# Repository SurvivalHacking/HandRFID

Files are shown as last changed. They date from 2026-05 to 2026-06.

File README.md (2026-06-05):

# HandRFID
Portable RFID tag reader-writer for filaments / Lettore-Scrittore di TAG RFID per filamenti

## 📘 Description / Descrizione

A small, portable device that allows you to quickly write RFID tags to label your spools. Compatible with QIDI and ANYCUBIC systems, but can be updated to support other standards as they become more widespread. / Un piccolo dispositivo portatile, che consente la scrittura rapida dei TAG RFID per battezzare le vostre bobine. Compatibile con sistemi QIDI e ANYCUBIC, ma aggiornabile per altri standard che prenderanno piede.

* Battery-powered / Funzionante a batterie
* Touchscreen / Touch Screen
* Material database / Database materiali
* Manufacturer database / Database costruttori
* Web-configurable / Configurabile via WEB
* Easy to implement / Facile da realizzare

Video tutorial (Italian): https://youtu.be/M0HzzsOZAlI 

Screenshot 2026-05-03 alle 01 08 40
Screenshot 2026-05-03 alle 01 08 11
Screenshot 2026-05-03 alle 01 07 57
Screenshot 2026-05-03 alle 01 07 41
Screenshot 2026-05-03 alle 01 07 27
Screenshot 2026-05-03 alle 01 05 34
Screenshot 2026-05-03 alle 01 05 09
Screenshot 2026-05-03 alle 01 04 54
Screenshot 2026-05-03 alle 01 14 26
Screenshot 2026-05-03 alle 01 13 25

## 👨‍💻 Programming / Programmazione

* WEB Programming (only for chrome) / Programmatore WEB (Solo per chrome): [https://youtu.be/M0HzzsOZAlI ](https://davidegatti.altervista.org/installaEsp32.php?progetto=HandRFID)

---
## 🎛️ Practical Assembly Guide / Schema pratico di assemblaggio

Schematic

---
## 🎛️ BOM / Elenco materiali

* PN532: https://s.click.aliexpress.com/e/_c30J9g7Z
* ESP32-2432S024R: https://s.click.aliexpress.com/e/_c3bvlCXF
* Mifare Classic 1K: https://s.click.aliexpress.com/e/_c3QRUTPz
* NTAG 213: https://s.click.aliexpress.com/e/_c3fpyESh
* Battery 803040 1000mA: https://s.click.aliexpress.com/e/_c4LtLOBT
* Link Affiliati

---
# 📝 Revisions / Revisioni

V1.0
* First Version / Prima versione

V1.1 - 21/02/2025
* Fixed some colour identification and minor bugs / Sistemati alcune rilevazioni colore e bug minori

V1.2 / V1.2C - 05/06/2026
* Added French Language / Aggiunta lingua francese

V1.2C - 05/06/2026 
* Special version for CYD ESP32-024 Clone / Versione speciale per CYD ESP32-024 Clone

---
## 🧾 License / Licenza

This project is licensed under
**Creative Commons Attribution-NonCommercial 4.0 International (CC BY-NC 4.0)**.

You may freely share and modify it, **citing the author**
(Davide Gatti / [survivalhacking](https://github.com/survivalhacking)) and Paolo Sambinello  **for non-commercial purposes**.

Questo progetto è distribuito con licenza
**Creative Commons – Attribuzione – Non Commerciale 4.0 Internazionale (CC BY-NC 4.0)**.

Puoi condividerlo e modificarlo liberamente, **citando l’autore**
(Davide Gatti / [survivalhacking](https://github.com/survivalhacking)) e Paolo Sambinello  **senza scopi commerciali**.

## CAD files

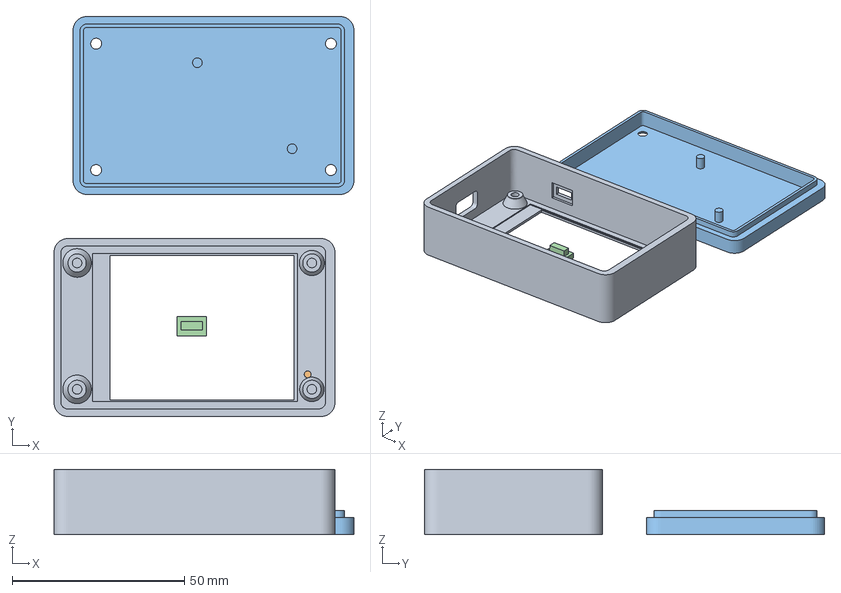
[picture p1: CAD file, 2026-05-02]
3D/BOX FULL (QIDI).3mf
87.1 x 116.2 x 18.9 mm
BOT
BOT-BIANCO
top
Pulsante.stl

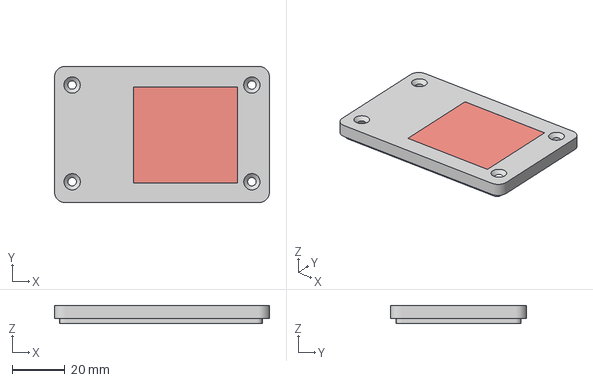
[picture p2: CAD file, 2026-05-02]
3D/BOT.3mf
81.6 x 51.7 x 7.00 mm
COLOR
Corpo26

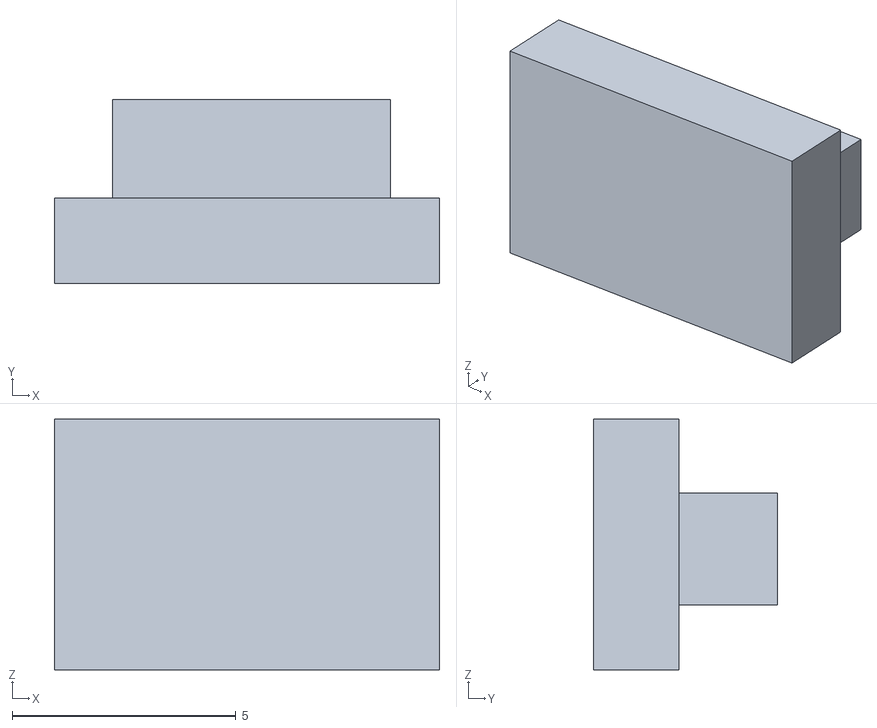
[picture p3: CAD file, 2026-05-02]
3D/Button.stl
8.60 x 4.10 x 5.60

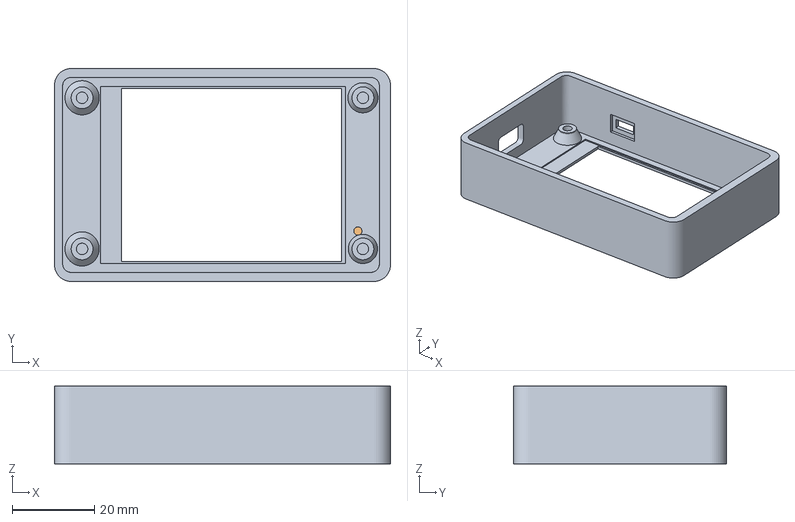
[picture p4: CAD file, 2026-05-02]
3D/TOP.3mf
81.6 x 51.7 x 18.9 mm
BOT
BOT-BIANCO

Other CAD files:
3D/BOX FULL (BAMBULAB).3mf
3D/BOX FULL (ANYCUBIC).3mf
3D/RFID.f3d

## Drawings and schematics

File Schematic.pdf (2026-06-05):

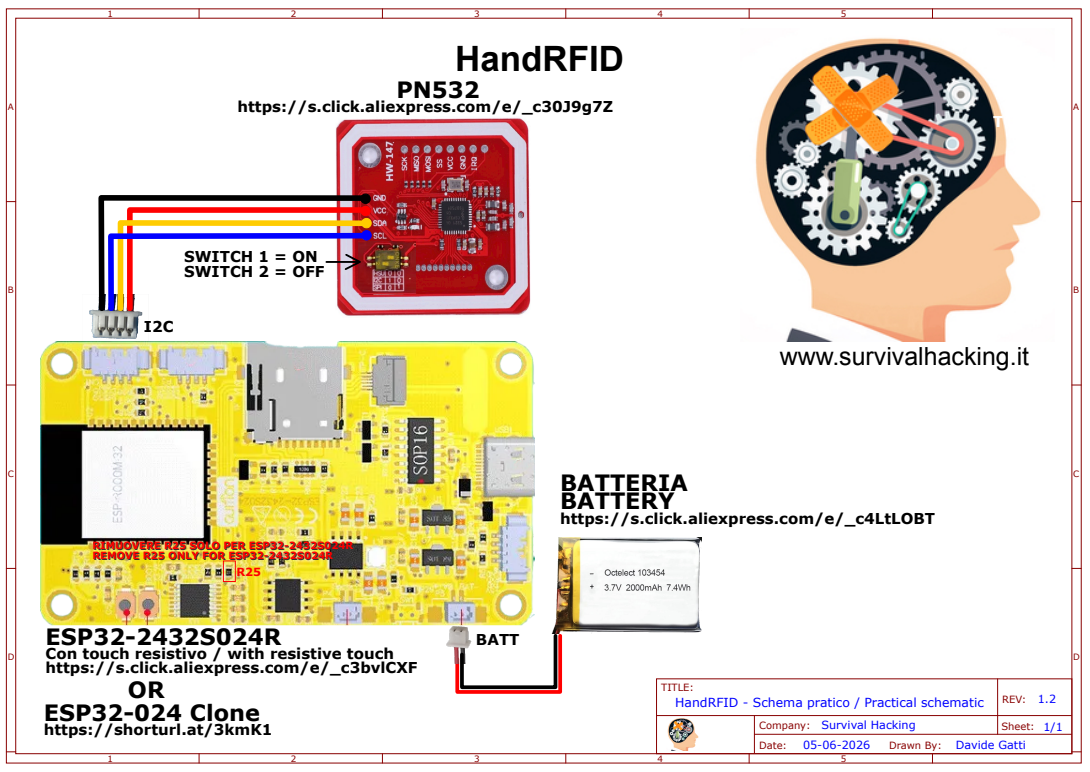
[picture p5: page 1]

https://s.click.aliexpress.com/e/_c30J9g7Z

BATTERIA
BATTERY
https://s.click.aliexpress.com/e/_c4LtLOBT

ESP32-2432S024R
Con touch resistivo / with resistive touch
https://s.click.aliexpress.com/e/_c3bvlCXF
ESP32-024 Clone
https://shorturl.at/3kmK1

TITLE: HandRFID - Schema pratico / Practical schematic | REV: 1.2

Company: Survival Hacking | Sheet: 1/1

Drawn By: Davide Gatti

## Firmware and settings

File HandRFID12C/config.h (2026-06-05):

// ============================================================
//  HandRFID-Touch – Hardware Configuration
//  Target boards: ESP32-2432S024R/C (2.4") / ESP32-2432S028R (2.8")
//  S024: resistive (XPT2046) + capacitive (CST820) auto-detect
//  S028: resistive only (XPT2046 on SPI bus separato)
//  Reconstructed from V2.1 firmware for S028R
// ============================================================
#pragma once

// ============================================================
//  DISPLAY SELECTION – uncomment ONE of the following
//  *** Cambiare anche in User_Setup.h (copiato nella libreria TFT_eSPI) ***
// ============================================================
#define DISPLAY_24    // ESP32-2432S024R/C – 2.4" CYD
// #define DISPLAY_28  // ESP32-2432S028R/C – 2.8" CYD

// ---- Validate selection ----
#if defined(DISPLAY_24) && defined(DISPLAY_28)
  #error "Select only ONE display: DISPLAY_24 or DISPLAY_28"
#elif !defined(DISPLAY_24) && !defined(DISPLAY_28)
  #error "Select a display: uncomment DISPLAY_24 or DISPLAY_28"
#endif

// ---------- Display (ILI9341 on HSPI) ----------
#define TFT_MOSI  13
#define TFT_MISO  12
#define TFT_SCLK  14
#define TFT_CS    15
#define TFT_DC     2
#define TFT_RST   -1          // tied to EN on CYD boards

// *** S024R/C vs S028R/C: backlight and I2C SDA are swapped ***
#ifdef DISPLAY_24
  #define TFT_BL    27
#else
  #define TFT_BL    21
#endif
#define TFT_BACKLIGHT_ON HIGH

// ---------- Touch – Resistive XPT2046 ----------
#define TOUCH_CS   33
#define TOUCH_IRQ  36

#ifdef DISPLAY_24
  // S024: touch condivide HSPI con il display (stessi MOSI/MISO/SCLK)
#else
  // S028: touch su bus SPI separato (pin dedicati)
  #define TOUCH_MOSI  32
  #define TOUCH_MISO  39
  #define TOUCH_CLK   25
#endif

// ---------- Touch – Capacitive CST820 (solo S024C, auto-detect) ----------
#ifdef DISPLAY_24
  #define CTP_SDA    33
  #define CTP_SCL    32
  #define CTP_RST    25
  #define CTP_INT    21
#endif

// ---------- I2C for PN532 NFC ----------
#ifdef DISPLAY_24
  #define I2C_SDA   21  //1        // S024R/C: GPIO 21
  #define I2C_SCL   22  //3        // same on both boards
#else
  #define I2C_SDA   27        // S028R/C: GPIO 27
  #define I2C_SCL   22          // same on both boards
#endif
#define PN532_I2C_ADDR 0x24

// ---------- RGB LED (active LOW on CYD) ----------
#define LED_R      4
#define LED_G     16
#define LED_B     17

// ---------- NVS namespace ----------
#define NVS_NAMESPACE "touch"

// ---------- Firmware version ----------
#ifdef DISPLAY_24C
  #define FW_VERSION "1.2C-S024C"
#elif defined(DISPLAY_24)
  #define FW_VERSION "1.2C-S024"
#else
  #define FW_VERSION "1.2C-S028"
#endif
// ---------- Display ----------
#define SCREEN_W 240
#define SCREEN_H 320

// ---------- MIFARE Classic 1K (QIDI) ----------
// QIDI usa sector 1 block 0 = absolute block 4
// Formato: byte[0]=Material code, byte[1]=Color code(1-24), byte[2]=Manufacturer(0=Generic,1=QIDI)
#define QIDI_DATA_BLOCK   4
// Keys da provare in ordine: {key[6], keyType} — keyType: 0=A, 1=B
#define QIDI_NUM_KEYS     8
struct QidiKeyEntry { uint8_t key[6]; uint8_t type; };
static const QidiKeyEntry QIDI_KEYS[QIDI_NUM_KEYS] = {
  {{0x1B, 0xFF, 0xFF, 0xFF, 0xFF, 0xFF}, 0},  // Key A primaria QIDI
  {{0x00, 0x00, 0x00, 0x00, 0x00, 0x00}, 1},  // Key B zeros (common)
  {{0xFF, 0xFF, 0xFF, 0xFF, 0xFF, 0xFF}, 0},  // Key A default factory
  {{0xFF, 0xFF, 0xFF, 0xFF, 0xFF, 0xFF}, 1},  // Key B default factory
  {{0xA0, 0xA1, 0xA2, 0xA3, 0xA4, 0xA5}, 0},  // Key A MAD
  {{0xD3, 0xF7, 0xD3, 0xF7, 0xD3, 0xF7}, 0},
  {{0x00, 0x00, 0x00, 0x00, 0x00, 0x00}, 0},  // Key A zeros
  {{0xB0, 0xB1, 0xB2, 0xB3, 0xB4, 0xB5}, 0},
};

// Codici materiale QIDI (NON sequenziali!)
struct QidiMatCode { const char* name; uint8_t code; };
#define QIDI_MAT_CODE_COUNT 36
static const QidiMatCode qidiMatCodes[QIDI_MAT_CODE_COUNT] = {
  {"PLA",        1}, {"PLA Matte",  2}, {"PLA Metal",  3}, {"PLA Silk",   4},
  {"PLA-CF",     5}, {"PLA-Wood",   6}, {"PLA-Basic",   7}, {"PLA-Matte Bas",  8},
  {"ABS",       11}, {"ABS-GF",    12}, {"ABS-Metal", 13}, {"ABS-OdorLess",  14},
  {"ASA",       18}, {"ASA-AERO",  19},
  {"PA",        24}, {"PA-CF",     25}, {"UltaPA-CF25", 26}, {"PA12-CF",     27},
  {"PAHT-CF",   30}, {"PAHT-GF",   31}, {"Supp.-PATH",  32}, {"Sup.-PET/PA", 33},
  {"PC/ABS-FR", 34},
  {"PET-CF",    37}, {"PET-GF",    38}, {"PETG-Basic",  39}, {"PETG-Tough",  40},
  {"PETG",      41}, {"PETG-CF",   42}, {"PETG Rapido", 43},
  {"PPS-CF",    44}, {"PETG-TR",   45}, {"PPS-GF",      46},
  {"PVA",       47}, {"TPU-Aero",  49},
  {"TPU",       50},
};

// Palette colori condivisa Qidi/Anycubic
// rgb = colore RGB24, qidiCode = codice Qidi 1-24 (0 = solo Anycubic)
struct ColorEntry { uint32_t rgb; uint8_t qidiCode; const char* nameEN; const char* nameIT; };
#define COLOR_PALETTE_COUNT 28
static const ColorEntry colorPalette[COLOR_PALETTE_COUNT] = {
  // --- Colori Qidi (qidiCode 1-24) ---
  {0xFAFAFA,  1, "White",       "Bianco"},
  {0x060606,  2, "Black",       "Nero"},
  {0xD9E3ED,  3, "Silver",      "Argento"},
  {0x5CF30F,  4, "Light Green", "Verde chiaro"},
  {0x63E492,  5, "Mint",        "Menta"},
  {0x2850FF,  6, "Blue",        "Blu"},
  {0xFE98FE,  7, "Pink",        "Rosa"},
  {0xDFD628,  8, "Yellow",      "Giallo"},
  {0x228332,  9, "Green",       "Verde"},
  {0x99DEFF, 10, "Light Blue",  "Azzurro"},
  {0x1714B0, 11, "Dark Blue",   "Blu scuro"},
  {0xCEC0FE, 12, "Lavender",    "Lavanda"},
  {0xCADE4B, 13, "Lime",        "Lime"},
  {0x1353AB, 14, "Royal Blue",  "Blu reale"},
  {0x5EA9FD, 15, "Sky Blue",    "Blu cielo"},
  {0xA878FF, 16, "Violet",      "Viola"},
  {0xFE717A, 17, "Rose",        "Rosato"},
  {0xFF362D, 18, "Red",         "Rosso"},
  {0xE2DFCD, 19, "Beige",       "Beige"},
  {0x898F9B, 20, "Gray",        "Grigio"},
  {0x6E3812, 21, "Brown",       "Marrone"},
  {0xCAC59F, 22, "Khaki",       "Kaki"},
  {0xF28636, 23, "Orange",      "Arancione"},
  {0xB87F2B, 24, "Bronze",      "Bronzo"},
  // --- Colori extra Anycubic (qidiCode = 0, no mapping Qidi) ---
  {0x00FFFF,  0, "Cyan",        "Ciano"},
  {0x8000FF,  0, "Purple",      "Porpora"},
  {0xFF69B4,  0, "Hot Pink",    "Rosa acceso"},
  {0xFFD700,  0, "Gold",        "Oro"},
};
#define MIFARE_BLOCKS 64
#define MIFARE_BLOCK_SIZE 16

// ---------- NTAG (Anycubic) – page layout ----------
#define ACE_PAGE_HEADER     4
#define ACE_PAGE_SKU        5   // 5-8   (20 bytes, 5 pages)
#define ACE_PAGE_BRAND     10   // 10-13 (16 bytes, 4 pages)
#define ACE_PAGE_TYPE      15   // 15-18 (16 bytes, 4 pages)
#define ACE_PAGE_COLOR     20   // 20    (4 bytes ABGR)
#define ACE_PAGE_EXT_TEMP  24   // 24    (4 bytes: min16LE + max16LE)
#define ACE_PAGE_BED_TEMP  29   // 29    (4 bytes: min16LE + max16LE)
#define ACE_PAGE_FILAMENT  30   // 30    (4 bytes: diameter16LE + length16LE)
#define ACE_PAGE_UNK       31   // 31    (E8 03 00 00)
#define ACE_HEADER_MAGIC   {0x7B, 0x00, 0x65, 0x00}
#define ACE_BRAND_DEFAULT  "AC"
#define ACE_SKU_LEN        20
#define ACE_STR_LEN        16

// ---------- WiFi (WiFiManager + web editor) ----------
#define WIFI_PORTAL_SSID "HandRFID-Setup"  // nome AP per config portal
#define WIFI_PORTAL_PASS "handrfid1"       // password AP config portal
#define WIFI_PORTAL_TIMEOUT 120            // secondi timeout config portal
#define WEB_PORT         80

// ---------- SPIFFS ----------
#define CSV_PATH         "/materials.csv"

// ---------- Material/Manufacturer DB ----------
#define MAX_MATERIALS       40
#define MAX_MANUFACTURERS   20
#define MAX_ACE_MATERIALS   20
#define MAT_NVS_NS   "matdb"
#define MFG_NVS_NS   "mfgdb"
#define MAT_KEY_FMT  "m%02u"

// ---------- Default manufacturers ----------
#define DEFAULT_MFG_1 "QIDI"
#define DEFAULT_MFG_2 "Anycubic"
#define DEFAULT_MFG_3 "Generic"

// ---------- Anycubic material entry (dynamic, loaded from SPIFFS) ----------
struct AceMatEntry {
  char     name[24];
  char     sku[24];
  uint16_t extMin, extMax;
  uint16_t bedMin, bedMax;
  bool     used;
};


// Weight -> length (meters) lookup
#define ACE_WEIGHT_COUNT 5
struct AceWeightEntry { const char* label; uint16_t grams; uint16_t meters; };
static const AceWeightEntry aceWeightDB[ACE_WEIGHT_COUNT] = {
  {"250g",   250,   82},
  {"500g",   500,  165},
  {"600g",   600,  198},
  {"750g",   750,  247},
  {"1000g", 1000,  330},
};

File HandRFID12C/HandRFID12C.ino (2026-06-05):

// ============================================================
//  HandRFID V1.2C
//  By Paolo Sambinello e Davide Gatti  www.survivalhacking.it
//  GITHUB: https://github.com/SurvivalHacking/handrfid
//
//  Dispositivo portatile per la gestione pratica dei TAG RFID delle bobine dei filamenti QIDI e ANYCUBIC / 
//  Handheld device for QIDI and ANYCUBIC reel RFID TAG 
//  * Gestione costruttori / Manufacturer management 
//  * Gestione Materiali / Material management
//  * Configurabile via WEB / Cofigurable via WEB
//  * Open Source e personalizzabile / Open source full customizable 
//
//  Elenco materiali / Bill of material
//  PN532: https://s.click.aliexpress.com/e/_c30J9g7Z (ATTENZIONE/WARNING  SW1=ON SW2=OFF)
//  ESP32-2432S024R: https://s.click.aliexpress.com/e/_c3bvlCXF
//  Batt. 803040 1000mA: https://s.click.aliexpress.com/e/_c4LtLOBT	
//
//  TAG Adesivi / adhesive TAG
//  Mifare Classic 1K: https://s.click.aliexpress.com/e/_c3QRUTPz
//  NTAG 213: https://s.click.aliexpress.com/e/_c3fpyESh
//
//  Copiare il file User_Setup.h nella cartella [utente]/documenti/arduino/libraries/TFT_eSPI	
//  Copy the file User_Setup.h on folder [users]/document/arduino/libraries/TFT_eSPI	
//
//  V1.0 15/03/2026 By Paolo Sambinello e Davide Gatti
//  Release iniziale / Initial release
//
//  V1.1 18/04/2026 by Davide Gatti
//  Sistemati alcuni problemi che facevano mostrare dati in modo non preciso. A volte mancava il costruttore e a volte il colore non aveva il nome ma un codice e non venivano rilevati correttamente i TAG vuoti
//
//  V1.2C 05/06/2022 by Davide Gatti
//  Aggiunta lingua Francese
//  Versione dedicata per il display CYD Clone ESP32-024  https://shorturl.at/3kmK1
//
// ============================================================




#include <Wire.h>
#include <SPI.h>
#include <Preferences.h>
#include <TFT_eSPI.h>
#include <XPT2046_Touchscreen.h>
#include <Adafruit_PN532.h>
#include <FS.h>
using namespace fs;        // espone File, FS nel global scope (richiesto da WebServer ESP32 core 3.x)
#include <SPIFFS.h>
#include <WiFi.h>
#include <WebServer.h>
#include <WiFiManager.h>
#include "qrcode.h"
#include <time.h>              // NTP time

#include "config.h"
#include "lang.h"
#include "utf8_latin1.h"
#include "FreeSans9pt8b.h"
#include "FreeSansBold12pt8b.h"
#include "webui.h"
#include "logo.h"
#ifdef DISPLAY_24
  #include "CST820.h"
#endif

// ---- Button struct (must be before any function using it) ----
struct Btn { int x, y, w, h; const char* label; uint16_t bg; };

// ---- Fonts (FreeSans = Arial equivalent) ----
// Inclusi tramite TFT_eSPI con LOAD_GFXFF abilitato
#define FONT_TITLE  &FreeSansBold12pt8b   // titoli / header (Latin-1 extended)
#define FONT_BODY   &FreeSans9pt8b        // testo normale (Latin-1 extended)
#define FONT_SMALL  &FreeSans9pt8b        // testo piccolo (Latin-1 extended)

// ---- Touch type ----
#ifdef DISPLAY_24
  enum TouchType { TOUCH_NONE, TOUCH_RESISTIVE, TOUCH_CAPACITIVE };
#else
  enum TouchType { TOUCH_NONE, TOUCH_RESISTIVE };  // S028: solo resistivo
#endif
TouchType touchType = TOUCH_NONE;

// ---- Globals ----
TFT_eSPI tft = TFT_eSPI();

// Font helpers (must be after tft declaration)
void setFontTitle() { tft.setFreeFont(FONT_TITLE); tft.setTextSize(1); }
void setFontBody()  { tft.setFreeFont(FONT_BODY);  tft.setTextSize(1); }
void setFontSmall() { tft.setFreeFont(FONT_SMALL); tft.setTextSize(1); }
void setFontBuiltin() { tft.setTextFont(1); tft.setTextSize(1); }

#ifdef DISPLAY_28
  // S028: touch XPT2046 su bus SPI dedicato (GPIO 32/39/25)
  SPIClass touchSPI(VSPI);
  XPT2046_Touchscreen ts(TOUCH_CS, TOUCH_IRQ);
#else
  // S024: touch XPT2046 condivide HSPI col display
  XPT2046_Touchscreen ts(TOUCH_CS, TOUCH_IRQ);
#endif

#ifdef DISPLAY_24
  // S024: capacitive CST820 (auto-detect)
  CST820 ctp(CTP_SDA, CTP_SCL, CTP_RST, -1);  // INT=-1 to avoid GPIO 21 conflict
#endif

Adafruit_PN532 nfc(-1, -1, &Wire);     // I2C mode on Wire (GPIO 21/22)
Preferences prefs;
WebServer server(WEB_PORT);

// ---- Dynamic material databases (loaded from SPIFFS CSV) ----
AceMatEntry aceMatList[MAX_ACE_MATERIALS];
uint8_t     aceMatCount = 0;

// ---- Debug log panel ----
#define DBG_MAX_LINES  10
#define DBG_LINE_LEN   36
char   dbgLines[DBG_MAX_LINES][DBG_LINE_LEN];
int    dbgCount = 0;    // quante righe totali scritte
int    dbgStart = 0;    // indice circolare della riga piu vecchia

// ---- State ----
bool   showDebugPanel = false;  // visibilita pannello debug (default OFF)
bool   wifiEnabled    = false;  // WiFi abilitato on-demand (default OFF)
bool   wifiConnected = false;
bool   webServerStarted = false;  // server.begin() chiamato solo dopo WiFi
Lang   curLang       = LANG_IT;
bool   displayInvert = false;
bool   autoMode      = false;
bool   nfcPresent    = false;
bool   nfcBusy       = false;
bool   hasCalib      = false;
int    calibMinX = 200, calibMaxX = 3900;
int    calibMinY = 200, calibMaxY = 3900;

// ---- Tag mode (QIDI vs Anycubic) ----
enum TagMode { TAG_QIDI, TAG_ANYCUBIC };
TagMode writeMode = TAG_QIDI;   // selected write mode
TagMode lastReadMode = TAG_QIDI; // detected on last read

// Current selection for writing (QIDI)
uint8_t selMfgIdx    = 0;   // manufacturer index
uint8_t selMatIdx    = 0;   // material index
uint8_t selColorIdx  = 0;   // color index

// Current selection for writing (Anycubic)
uint8_t selAceMatIdx    = 0;  // index into aceMatList
uint8_t selAceWeightIdx = 2;  // index into aceWeightDB (default 600g)
uint8_t selAceColorIdx  = 1;          // index into colorPalette (default Black)
String   selAceBrand    = "AC";       // "AC" = Anycubic, "GEN" = Generic

// Scroll offset (shared across list screens, reset on screen change)
int scrollOffset = 0;

// Timers
unsigned long lastTouchTime = 0;
unsigned long lastActivityTime = 0;
unsigned long screensaverTimeout = 120000;  // 2 minuti in ms (configurabile via web, in secondi)
bool   rainbowEnabled  = true;   // titolo rainbow on/off
uint8_t backlightLevel = 255;    // luminosita backlight (0-255)

// ---- UI State machine ----
enum Screen {
  SCR_MAIN,
  SCR_READ_RESULT,
  SCR_WRITE_SELECT_MFG,
  SCR_WRITE_SELECT_MAT,
  SCR_WRITE_SELECT_COLOR,
  SCR_WRITING,
  SCR_SETUP,
  SCR_LANG_SELECT,
  SCR_CALIBRATE,
  SCR_KEYBOARD,
  SCR_MFG_LIST,
  SCR_MAT_LIST,
  SCR_MFG_EDIT,
  SCR_MAT_EDIT,
  SCR_CONFIRM,
  SCR_NOTICE,
  SCR_WRITE_SELECT_MODE,    // QIDI or Anycubic
  SCR_ACE_SELECT_MFG,       // Anycubic manufacturer (AC/GEN)
  SCR_ACE_SELECT_MAT,       // Anycubic material
  SCR_ACE_SELECT_COLOR,     // Anycubic color (hex input)
  SCR_ACE_SELECT_WEIGHT,    // Anycubic spool weight
  SCR_SCREENSAVER,          // orologio screensaver dopo inattivita
  SCR_WRITE_DONE,           // post-write: ristampa o menu
};
Screen curScreen = SCR_MAIN;
Screen prevScreen = SCR_MAIN;

// ---- Manufacturer / Material DB (NVS) ----
struct MfgEntry  { char name[24]; bool used; };
struct MatEntry  {
  char     name[24];
  char     sku[24];
  uint8_t  code;       // QIDI material code (1-50)
  uint16_t extMin, extMax;
  uint16_t bedMin, bedMax;
  bool     used;
};
MfgEntry mfgDB[MAX_MANUFACTURERS];
MatEntry matDB[MAX_MATERIALS];
uint8_t  mfgCount = 0;
uint8_t  matCount = 0;

// ---- Tag data ----
uint8_t tagUID[7];
uint8_t tagUIDLen = 0;
uint8_t tagBlock[16];
bool    tagPresent = false;

// ---- Read tag decoded fields (QIDI) ----
String  readMfg, readMat, readColor;
uint8_t readMfgIdx, readMatIdx, readColorIdx;

// ---- Read tag decoded fields (Anycubic) ----
String   aceReadSku, aceReadBrand, aceReadType;
uint32_t aceReadColor = 0;          // ABGR
uint16_t aceReadExtMin, aceReadExtMax;
uint16_t aceReadBedMin, aceReadBedMax;
uint16_t aceReadDiameter, aceReadLength;


// ---- Notice ----
String noticeText;
Screen noticeReturn;

// ---- Confirm ----
String confirmText;
typedef void (*ConfirmCallback)(bool);
ConfirmCallback confirmCb = nullptr;

// ---- Forward declarations ----
void drawMainScreen();
void drawSetupScreen();
void drawLangSelect();
void drawCalibScreen();
void drawReadResult(bool showBack = true);
void drawWriteSelectMfg();
void drawWriteSelectMat();
void drawWriteSelectColor();
void drawNotice();
void drawConfirm();
void drawWriteSelectMode();
void drawAceSelectMfg();
void drawAceSelectMat();
void drawAceSelectColor();
void drawAceSelectWeight();
void drawWriteDone();
void drawReadResultAnycubic(bool showBack = true);
void handleTouch(int x, int y);
bool nfcReselect(uint8_t* uid, uint8_t* uidLen);
bool readTag();
bool readTagInternal(uint8_t* uid, uint8_t uidLen);
bool writeTag();
bool readTagAnycubic();
bool readTagAnycubicInternal(uint8_t* uid, uint8_t uidLen);
bool writeTagAnycubic();
bool readTagOnce();
bool readTagValidated();
bool readTagAuto();
void loadSettings();
void saveSettings();
void loadMfgDB();
void saveMfgDB();
void loadMatDB();
void saveMatDB();
void initDefaultMfg();
void initDefaultMat();
void setBacklight(uint8_t brightness);
void showStatus(const char* msg, uint16_t color = TFT_WHITE);
void startWebServer();
void connectWifi();
void disconnectWifi();
void ledOrange();
void ledOff();
void ledBlinkBlue();

// ================================================================
//  Backlight
// ================================================================
void setBacklight(uint8_t brightness) {
  analogWrite(TFT_BL, brightness);
}

// LED flash: lampeggia 3 volte velocemente (active LOW)
void ledFlash(uint8_t pin, int count = 3, int onMs = 80, int offMs = 80) {
  for (int i = 0; i < count; i++) {
    digitalWrite(pin, LOW);   // ON
    delay(onMs);
    digitalWrite(pin, HIGH);  // OFF
    if (i < count - 1) delay(offMs);
  }
}
void ledFlashOk()   { ledFlash(LED_G); }  // verde = successo
void ledFlashErr()  { ledFlash(LED_R); }  // rosso = errore

// ================================================================
//  NVS – Settings
// ================================================================
void loadSettings() {
  prefs.begin(NVS_NAMESPACE, true);
  curLang       = (Lang)prefs.getUChar("lang", LANG_IT);
  if (curLang >= LANG_COUNT) curLang = LANG_IT;
  displayInvert = prefs.getBool("dinv", false);
  autoMode      = prefs.getBool("auto", false);
  hasCalib      = prefs.getBool("hascal", false);
  calibMinX     = prefs.getInt("minx", 200);
  calibMaxX     = prefs.getInt("maxx", 3900);
  calibMinY     = prefs.getInt("miny", 200);
  calibMaxY     = prefs.getInt("maxy", 3900);
  screensaverTimeout = prefs.getULong("sstout", 120000);
  rainbowEnabled     = prefs.getBool("rainbow", true);
  backlightLevel     = prefs.getUChar("blight", 255);
  showDebugPanel     = prefs.getBool("dbgpanel", false);
  prefs.end();
}

void saveSettings() {
  prefs.begin(NVS_NAMESPACE, false);
  prefs.putUChar("lang", (uint8_t)curLang);
  prefs.putBool("dinv", displayInvert);
  prefs.putBool("auto", autoMode);
  prefs.putBool("hascal", hasCalib);
  prefs.putInt("minx", calibMinX);
  prefs.putInt("maxx", calibMaxX);
  prefs.putInt("miny", calibMinY);
  prefs.putInt("maxy", calibMaxY);
  prefs.putULong("sstout", screensaverTimeout);
  prefs.putBool("rainbow", rainbowEnabled);
  prefs.putUChar("blight", backlightLevel);
  prefs.putBool("dbgpanel", showDebugPanel);
  prefs.end();
}

// ================================================================
//  NVS – Manufacturer DB
// ================================================================
void loadMfgDB() {
  prefs.begin(MFG_NVS_NS, true);
  mfgCount = 0;
  for (int i = 0; i < MAX_MANUFACTURERS; i++) {
    char key[8];
    snprintf(key, sizeof(key), "m%02u", i);
    String val = prefs.getString(key, "");
    if (val.length() > 0) {
      strncpy(mfgDB[mfgCount].name, val.c_str(), 23);
      mfgDB[mfgCount].name[23] = 0;
      mfgDB[mfgCount].used = true;
      mfgCount++;
    }
  }
  prefs.end();
  if (mfgCount == 0) initDefaultMfg();
}

void saveMfgDB() {
  prefs.begin(MFG_NVS_NS, false);
  prefs.clear();
  for (int i = 0; i < mfgCount; i++) {
    char key[8];
    snprintf(key, sizeof(key), "m%02u", i);
    prefs.putString(key, mfgDB[i].name);
  }
  prefs.end();
}

void initDefaultMfg() {
  // Clear any stale entries beyond the defaults
  for (int i = 0; i < MAX_MANUFACTURERS; i++) {
    memset(mfgDB[i].name, 0, sizeof(mfgDB[i].name));
    mfgDB[i].used = false;
  }
  mfgCount = 3;
  strncpy(mfgDB[0].name, DEFAULT_MFG_1, 23); mfgDB[0].used = true;
  strncpy(mfgDB[1].name, DEFAULT_MFG_2, 23); mfgDB[1].used = true;
  strncpy(mfgDB[2].name, DEFAULT_MFG_3, 23); mfgDB[2].used = true;
  saveMfgDB();
}

// ================================================================
//  NVS – Material DB
// ================================================================
void loadMatDB() {
  prefs.begin(MAT_NVS_NS, true);
  matCount = 0;
  for (int i = 0; i < MAX_MATERIALS; i++) {
    char key[8];
    snprintf(key, sizeof(key), MAT_KEY_FMT, i);
    String val = prefs.getString(key, "");
    if (val.length() > 0) {
      strncpy(matDB[matCount].name, val.c_str(), 23);
      matDB[matCount].name[23] = 0;
      matDB[matCount].used = true;
      matCount++;
    }
  }
  prefs.end();
  if (matCount == 0) initDefaultMat();
}

void saveMatDB() {
  prefs.begin(MAT_NVS_NS, false);
  prefs.clear();
  for (int i = 0; i < matCount; i++) {
    char key[8];
    snprintf(key, sizeof(key), MAT_KEY_FMT, i);
    prefs.putString(key, matDB[i].name);
  }
  prefs.end();
}

void initDefaultMat() {
  matCount = min((int)NUM_DEFAULT_MATERIALS, MAX_MATERIALS);
  for (int i = 0; i < matCount; i++) {
    strncpy(matDB[i].name, defaultMaterials[i], 23);
    matDB[i].name[23] = 0;
    matDB[i].used = true;
  }
  saveMatDB();
}

// ================================================================
//  Touch abstraction
//  S024: resistive XPT2046 / capacitive CST820 (auto-detect)
//  S028: resistive XPT2046 only
// ================================================================
bool touchIsTouched() {
  if (touchType == TOUCH_RESISTIVE)
    return ts.touched();
#ifdef DISPLAY_24
  if (touchType == TOUCH_CAPACITIVE) {
    uint16_t x, y; uint8_t g;
    return ctp.getTouch(&x, &y, &g);
  }
#endif
  return false;
}

void touchGetPoint(int &x, int &y) {
  if (touchType == TOUCH_RESISTIVE) {
    TS_Point p = ts.getPoint();
#ifdef DISPLAY_24C
    // Clone: calibMinX/MaxX=rawY, calibMinY/MaxY=rawX, entrambi specchiati
    int tx = map(p.y, calibMinX, calibMaxX, 0, SCREEN_W);
    int ty = map(p.x, calibMinY, calibMaxY, 0, SCREEN_H);
    x = constrain(SCREEN_W - 1 - tx, 0, SCREEN_W - 1);
    y = constrain(SCREEN_H - 1 - ty, 0, SCREEN_H - 1);
#else
    int tx = map(p.x, calibMinX, calibMaxX, 0, SCREEN_W);
    int ty = map(p.y, calibMinY, calibMaxY, 0, SCREEN_H);
    x = constrain(tx, 0, SCREEN_W - 1);
    y = constrain(ty, 0, SCREEN_H - 1);
#endif
  }
#ifdef DISPLAY_24
  else if (touchType == TOUCH_CAPACITIVE) {
    uint16_t cx, cy; uint8_t g;
    ctp.getTouch(&cx, &cy, &g);
    // CST820 returns 240x320 natively; portrait mode — direct mapping
    x = cx;
    y = cy;
    x = constrain(x, 0, SCREEN_W - 1);
    y = constrain(y, 0, SCREEN_H - 1);
  }
#endif
}

void touchGetRaw(int &x, int &y) {
  if (touchType == TOUCH_RESISTIVE) {
    TS_Point p = ts.getPoint();
    x = p.x;
    y = p.y;
  }
#ifdef DISPLAY_24
  else if (touchType == TOUCH_CAPACITIVE) {
    uint16_t cx, cy; uint8_t g;
    ctp.getTouch(&cx, &cy, &g);
    x = cx;
    y = cy;
  }
#endif
}

// ================================================================
//  Status bar helper
// ================================================================
void showStatus(const char* msg, uint16_t color) {
  tft.fillRect(0, SCREEN_H - 28, SCREEN_W, 28, TFT_BLACK);
  tft.setTextColor(color, TFT_BLACK);
  setFontBody();
  tft.setTextDatum(MC_DATUM);
  tft.drawString(L1(msg), SCREEN_W / 2, SCREEN_H - 14);
}

// ================================================================
//  Debug log panel (main screen only)
// ================================================================
// Area del pannello: sotto il bottone Write, sopra il bottone Setup
#define DBG_X       4
#define DBG_Y       180
#define DBG_W       (SCREEN_W - 8)
#define DBG_H       (SCREEN_H - 48 - DBG_Y)   // lascia spazio per setup + info
#define DBG_LINE_H  10

void drawDebugPanel() {
  // Cornice
  tft.fillRect(DBG_X, DBG_Y, DBG_W, DBG_H, TFT_BLACK);
  tft.drawRect(DBG_X, DBG_Y, DBG_W, DBG_H, TFT_DARKGREY);

  // Titoletto
  tft.setTextFont(1); tft.setTextSize(1);
  tft.setTextColor(TFT_DARKGREY, TFT_BLACK);
  tft.setTextDatum(TL_DATUM);
  tft.drawString("LOG", DBG_X + 3, DBG_Y + 2);
  tft.drawFastHLine(DBG_X + 1, DBG_Y + 11, DBG_W - 2, TFT_DARKGREY);

  // Righe di log
  int maxVisible = (DBG_H - 14) / DBG_LINE_H;
  int total = min(dbgCount, DBG_MAX_LINES);
  int startLine = (total > maxVisible) ? total - maxVisible : 0;

  tft.setTextColor(TFT_GREEN, TFT_BLACK);
  for (int i = startLine; i < total; i++) {
    int lineIdx = (dbgStart + i) % DBG_MAX_LINES;
    int py = DBG_Y + 13 + (i - startLine) * DBG_LINE_H;
    tft.drawString(dbgLines[lineIdx], DBG_X + 3, py);
  }
}

void debugLog(const char* msg) {
  // Aggiungi al buffer circolare
  int slot;
  if (dbgCount < DBG_MAX_LINES) {
    slot = dbgCount;
  } else {
    slot = dbgStart;
    dbgStart = (dbgStart + 1) % DBG_MAX_LINES;
  }
  strncpy(dbgLines[slot], msg, DBG_LINE_LEN - 1);
  dbgLines[slot][DBG_LINE_LEN - 1] = 0;
  if (dbgCount < DBG_MAX_LINES) dbgCount++;

  // Ridisegna il pannello solo se siamo nella main screen E il pannello è abilitato
  if (curScreen == SCR_MAIN && showDebugPanel) drawDebugPanel();
}

void debugClear() {
  dbgCount = 0;
  dbgStart = 0;
  if (curScreen == SCR_MAIN && showDebugPanel) drawDebugPanel();
}

void debugLogf(const char* fmt, ...) {
  char buf[DBG_LINE_LEN];
  va_list args;
  va_start(args, fmt);
  vsnprintf(buf, sizeof(buf), fmt, args);
  va_end(args);
  debugLog(buf);
}

// ================================================================
//  Button helper
// ================================================================

// ================================================================
//  Button rendering — gradiente + effetto rilievo 3D
// ================================================================

// Estrae componenti R,G,B da RGB565
inline void rgb565ToRgb(uint16_t c, uint8_t &r, uint8_t &g, uint8_t &b) {
  r = (c >> 11) << 3;
  g = ((c >> 5) & 0x3F) << 2;
  b = (c & 0x1F) << 3;
}

// Crea RGB565 da componenti (con clamp)
inline uint16_t rgbToRgb565b(int r, int g, int b) {
  r = constrain(r, 0, 255);
  g = constrain(g, 0, 255);
  b = constrain(b, 0, 255);
  return ((r & 0xF8) << 8) | ((g & 0xFC) << 3) | (b >> 3);
}

// Schiarisce un colore RGB565 di `amount` (0-255)
uint16_t colorLighten(uint16_t c, int amount) {
  uint8_t r, g, b;
  rgb565ToRgb(c, r, g, b);
  return rgbToRgb565b(r + amount, g + amount, b + amount);
}

// Scurisce un colore RGB565 di `amount`
uint16_t colorDarken(uint16_t c, int amount) {
  uint8_t r, g, b;
  rgb565ToRgb(c, r, g, b);
  return rgbToRgb565b(r - amount, g - amount, b - amount);
}

// Interpola tra due colori RGB565 (t=0..steps)
uint16_t colorLerp(uint16_t c1, uint16_t c2, int t, int steps) {
  uint8_t r1, g1, b1, r2, g2, b2;
  rgb565ToRgb(c1, r1, g1, b1);
  rgb565ToRgb(c2, r2, g2, b2);
  int r = r1 + (int)(r2 - r1) * t / steps;
  int g = g1 + (int)(g2 - g1) * t / steps;
  int b = b1 + (int)(b2 - b1) * t / steps;
  return rgbToRgb565b(r, g, b);
}
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
void loop() {
  // Touch handling with debounce
  static bool calibPrinted = false;
  if (!calibPrinted) {
    Serial.printf("CALIB: minX=%d maxX=%d minY=%d maxY=%d\n", calibMinX, calibMaxX, calibMinY, calibMaxY);
    calibPrinted = true;
  }

/*
// TEST - rimuovere dopo
if (ts.touched()) {
  TS_Point p = ts.getPoint();
  int tx = map(p.x, calibMinX, calibMaxX, 0, SCREEN_W);
  int ty = map(p.y, calibMinY, calibMaxY, 0, SCREEN_H);
  int fx = constrain(SCREEN_W - 1 - ty, 0, SCREEN_W - 1);
  int fy = constrain(tx, 0, SCREEN_H - 1);
  Serial.printf("RAW x=%d y=%d | mapped tx=%d ty=%d | final x=%d y=%d\n", 
                p.x, p.y, tx, ty, fx, fy);
}
*/

  if (touchIsTouched() && millis() - lastTouchTime > 250) {
    lastTouchTime = millis();
    lastActivityTime = millis();
    int tx, ty;
    touchGetPoint(tx, ty);
    // Se siamo in power-off (screensaver), qualsiasi touch riaccende e torna alla main
    if (curScreen == SCR_SCREENSAVER) {
      setBacklight(backlightLevel);
      while (touchIsTouched()) delay(10);
      drawMainScreen();
    } else {
      Serial.printf("TOUCH x=%d y=%d scr=%d scroll=%d\n", tx, ty, curScreen, scrollOffset);
      handleTouch(tx, ty);
      // Wait for release
      while (touchIsTouched()) delay(10);
    }
  }

  // Auto power-off dopo timeout di inattivita: display nero + backlight spenta (0 = mai)
  if (screensaverTimeout > 0 && curScreen != SCR_SCREENSAVER
      && millis() - lastActivityTime > screensaverTimeout) {
    curScreen = SCR_SCREENSAVER;
    tft.fillScreen(TFT_BLACK);
    setBacklight(0);
    ledOff();   // spegni LED per sicurezza
  }

  // Rainbow title animation (~10 fps, solo se abilitato)
  if (rainbowEnabled && curScreen == SCR_MAIN && millis() - lastRainbowUpdate > 100) {
    lastRainbowUpdate = millis();
    rainbowHueOffset = (rainbowHueOffset + 5) % 360;
    drawRainbowTitle();
  }

  // Auto mode
  autoModeLoop();

  // Web server (solo se avviato, cioè dopo connessione WiFi)
  if (webServerStarted) server.handleClient();

  delay(10);
}

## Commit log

2026-05-02 Expand README with project details and resources
    Added detailed description, programming info, BOM, revisions, and license information.
2026-05-02 Practical Assembly Schematic / Schema pratico
2026-05-02 Bill of material / elenco materiali
2026-05-02 3D printer files
    [BOT.3mf, BOX FULL (ANYCUBIC).3mf, BOX FULL (BAMBULAB).3mf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]
2026-05-02 Arduino Ide Sketch
2026-06-05 Arduino Ide Sketch V1.2 for ESP32-2432S024
2026-06-05 Arduino Ide Sketch V1.1 for ESP32-2432S024
2026-06-05 Arduino Ide Sketch V1.2C for ESP32-024 CYD (Clone)
2026-06-05 Practical Schematic / Schema prtiaco
